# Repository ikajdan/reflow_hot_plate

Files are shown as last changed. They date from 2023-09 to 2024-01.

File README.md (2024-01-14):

<h1 align="center">
  Reflow Hot Plate
  <br><br>
  Reflow Hot Plate
  <br><br>
</h1>

<p align="center">
  <a href="#features">Features</a> •
  <a href="#hardware">Hardware</a> •
  <a href="#firmware">Firmware</a> •
  <a href="#usage">Usage</a> •
  <a href="#gallery">Gallery</a> •
  <a href="#license">License</a>
</p>

The STM32-Based Reflow Hot Plate Project is an open-source initiative aimed at creating a reflow soldering hot plate using the STM32 microcontroller. This project provides an affordable and customizable solution for hobbyists looking to solder surface-mount components onto printed circuit boards with precision and control.

## Features

- **Precise temperature control:** The STM32 microcontroller provides accurate temperature control, ensuring optimal soldering results for a wide range of solder pastes and components.
- **User-friendly interface:** A user-friendly interface, featuring an OLED display and tactile buttons, allows you to easily set and monitor reflow profiles.
- **Customizable reflow profiles:** Create, edit, and save reflow profiles tailored to your specific soldering requirements.
- **Safety mechanisms:** Built-in safety features, such as over-temperature protection and emergency shut-off, ensure a secure soldering environment.
- **Open-source:** The entire project, including schematics, PCB layouts, and firmware is open-source and available for improvement and customization.

## Hardware

The electronic hardware is designed using KiCad. It includes the following components:

- STM32 microcontroller (STM32F103 series)
- N-Channel Power MOSFET for controlling the heating element
- Thermocouple and PT100 sensor for temperature measurement
- OLED display for real-time temperature and soldering progress information
- Buttons for user interaction
- USB-C connector for communication
- Power supply circuitry

The mechanical hardware is designed using FreeCAD. It includes the following components:

- Front panel mask
- Front panel brackets
- Gooseneck mounting

These components are designed to be 3D printed and assembled together to create a complete device.

For detailed hardware schematics, PCB layout and CAD models, please refer to the [Hardware](hardware/) directory.

## Firmware

The firmware for the reflow hot plate is developed using the STM32CubeIDE. It includes:

- Temperature control algorithm
- User interface logic
- Reflow profile management
- Safety and emergency handling

The Cube project can be found in the [Firmware](firmware/) directory.

## Usage

1. Power on the reflow hot plate and wait for it to initialize.
1. Place your PCB with solder paste and components onto the hot plate.
1. Use the tactile buttons and OLED display to navigate through the user interface and select a reflow profile.
1. The hot plate will execute the selected reflow profile, precisely controlling the temperature to solder the components onto the PCB.
1. Once the reflow process is complete, allow the PCB to cool before removing it from the hot plate.

## Gallery








## License

This project is licensed under the [MIT License](LICENSE.md), which means you are free to use, modify, and distribute the project's source code and documentation for both commercial and non-commercial purposes.

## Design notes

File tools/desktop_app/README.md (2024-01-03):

# Reflow Hot Plot

Allows visualizing the temperature profile of a reflow soldering process.

### Usage

```bash
python reflow_hot_plot.py <serial_port>
```

### Testing

1. Set up a virtual serial port: `socat -d -d pty,raw,echo=0 pty,raw,echo=0`
1. Start the application: `python reflow_hot_plot.py /dev/pts/1`
1. Run the device emulator: `python device_emulator.py /dev/pts/2`

## API Specification

The API specification for communication between a dedicated desktop application and the device via the USB CDC interface.

### Send

Commands for controlling the device.

- 1 - starts the soldering procedure `[char]`.
- 0 - stops the soldering procedure `[char]`.

### Receive

Data received from the device.

- Duration - time in seconds since the start of the soldering procedure `[int]`.
- TC - thermocouple temperature in centigrade `[int]`.
- RTD - RTD temperature in centigrade `[int]`.
- Temperature - measured temperature in centigrade `[int]`.
- TargetTemperature - reference temperature in degrees Celsius `[int]`.
- Name - profile name `[string]`.
- Stage - heating stage (0=preheat, 1=soak, 2=reflow, 3=cooldown, 4=idle) `[int]`.
- State - device state (0=welcome, 1=menu, 2=precheck, 3=heating, 4=done, 5=aborted, 6=error) `[int]`.

Example message:

```json
{
  "Duration": 1098,
  "TC": 2350,
  "RTD": 2101,
  "Temperature": 2350,
  "TargetTemperature": 0,
  "Name": "DSP863",
  "Stage": 0,
  "State": 3
}
```

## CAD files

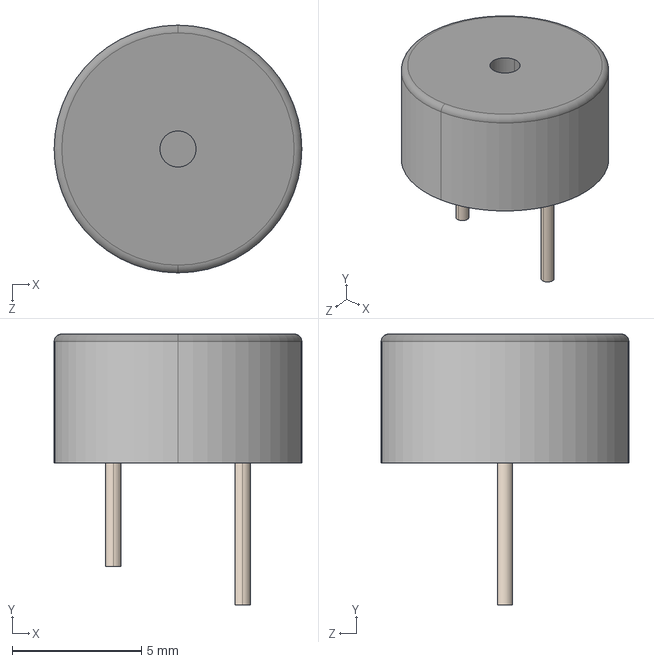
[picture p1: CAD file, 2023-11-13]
hardware/control_board/models/CMI-9605IC-0380T.step
9.60 x 10.5 x 9.60 mm

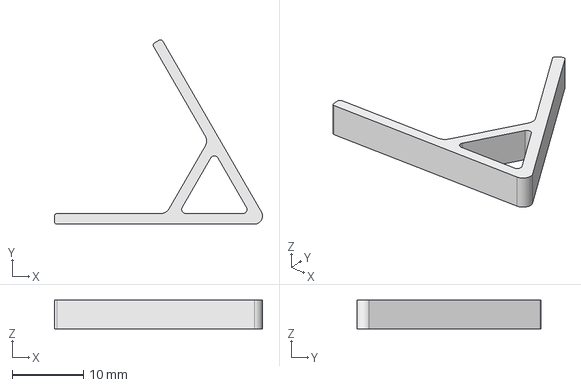
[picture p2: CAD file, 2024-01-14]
hardware/mechanical_parts/front_panel_bracket.FCStd
29.2 x 25.9 x 4.00 mm

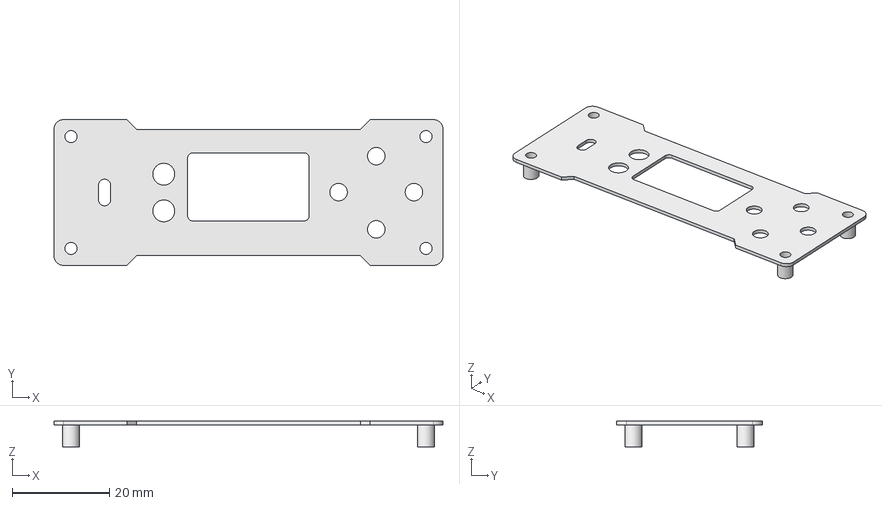
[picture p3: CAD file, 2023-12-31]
hardware/mechanical_parts/front_panel_mask.FCStd
80.0 x 30.0 x 5.30 mm

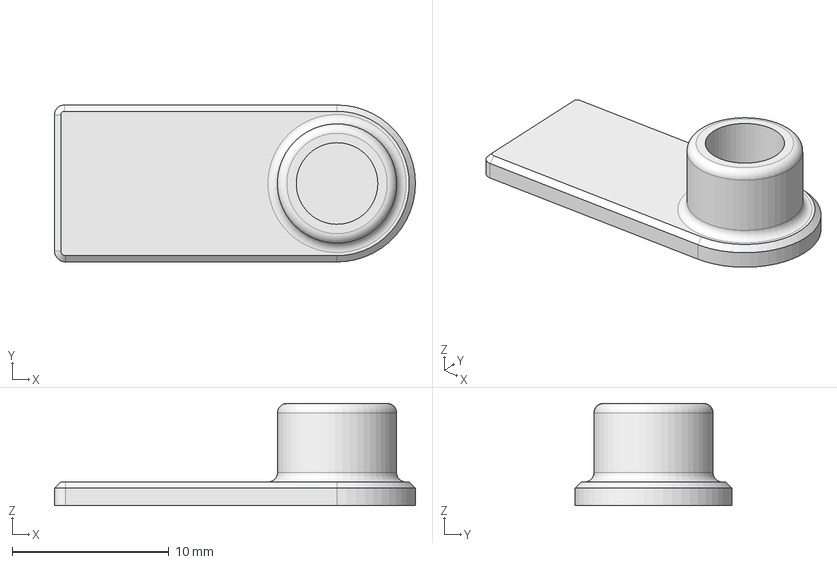
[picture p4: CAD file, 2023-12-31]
hardware/mechanical_parts/gooseneck_mounting.FCStd
23.0 x 10.00 x 6.50 mm

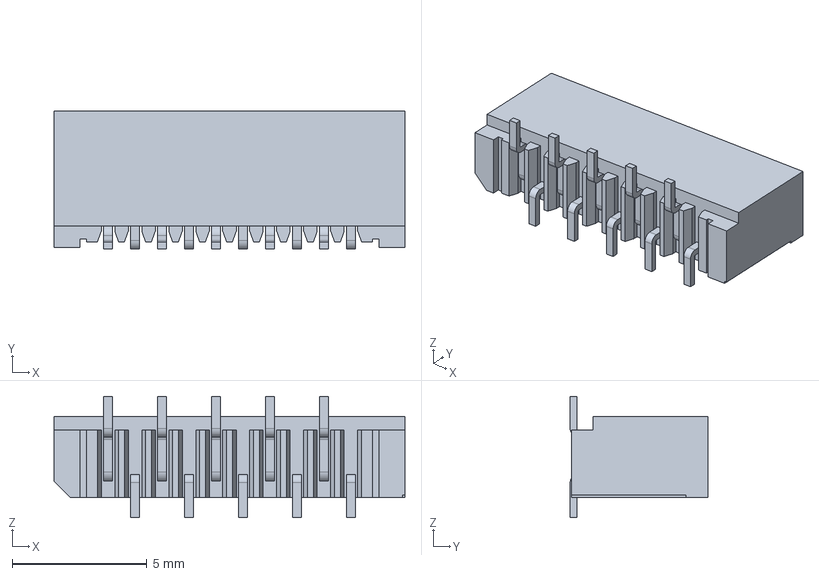
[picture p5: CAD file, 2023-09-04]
hardware/front_panel/models/52808-1070.step
13.0 x 5.10 x 4.50 mm

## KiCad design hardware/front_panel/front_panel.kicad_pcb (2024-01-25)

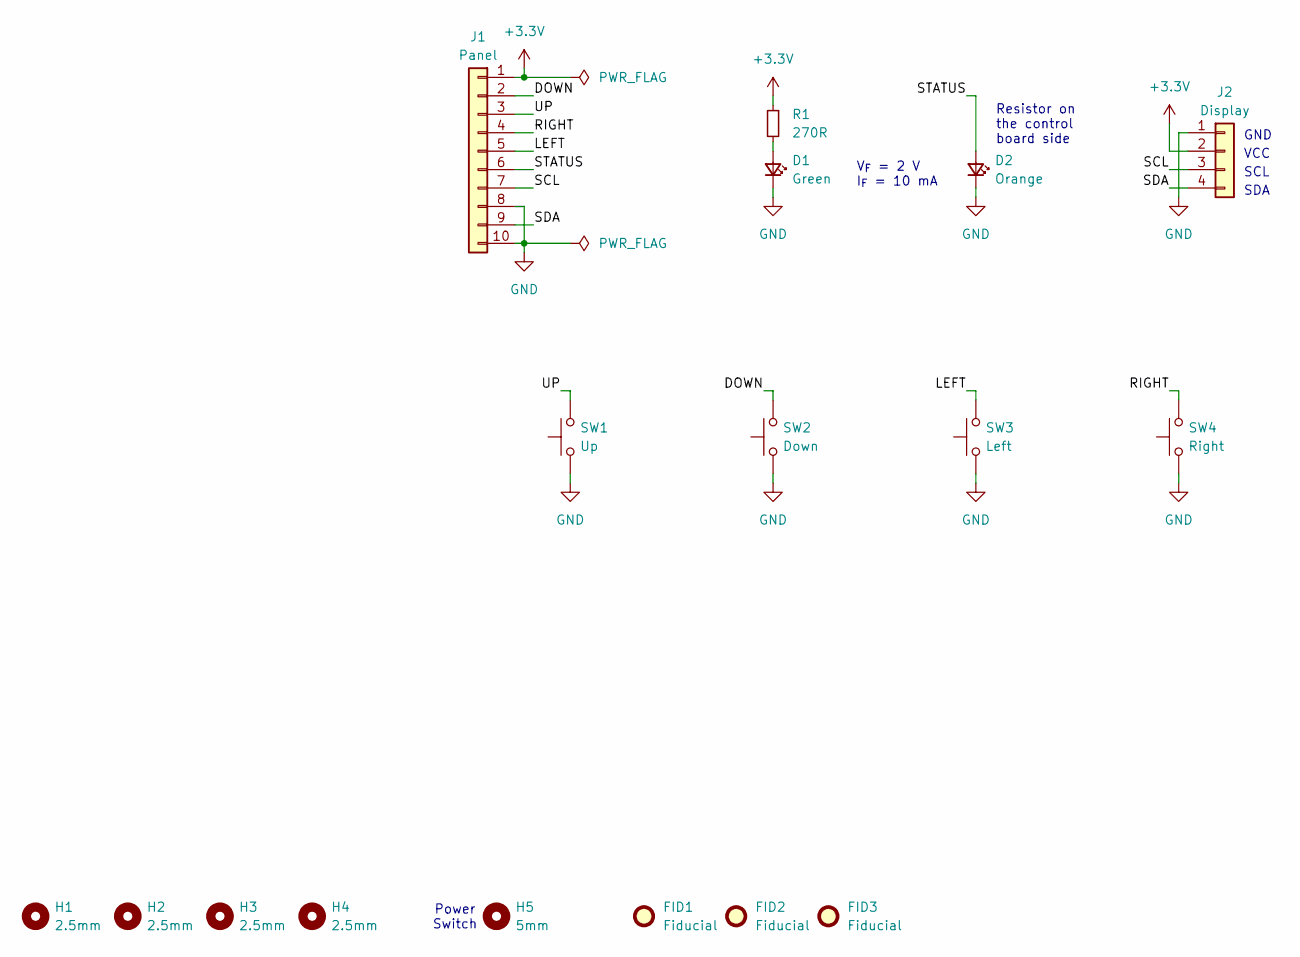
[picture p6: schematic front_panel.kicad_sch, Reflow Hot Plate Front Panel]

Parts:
D1: Green; LED_D3.0mm_FlatTop
D2: Orange; LED_D3.0mm_FlatTop
FID1, FID2, FID3: Fiducial; Fiducial_1mm_Mask2mm
H1, H2, H3, H4: 2.5mm; MountingHole_2.5mm
H5: 5mm; MountingHole_5mm
J1: Panel; 52808-1070
J2: Display; 0.96_OLED
R1: 270R; R_0603_1608Metric
SW1: Up; SW_PUSH_6mm_H7.3mm
SW2: Down; SW_PUSH_6mm_H7.3mm
SW3: Left; SW_PUSH_6mm_H7.3mm
SW4: Right; SW_PUSH_6mm_H7.3mm

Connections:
+3.3V: J1.1, J2.2, R1.1
/DOWN: J1.2, SW2.2
/LEFT: J1.5, SW3.2
/RIGHT: J1.4, SW4.2
/SCL: J1.7, J2.3
/SDA: J1.9, J2.4
/STATUS: D2.2 (A), J1.6
/UP: J1.3, SW1.2
GND: D1.1 (K), D2.1 (K), J1.8, J1.10, J2.1, SW1.1, SW2.1, SW3.1, SW4.1
unnamed: D1.2 (A), R1.2

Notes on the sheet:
Resistor on the control board side
Power Switch
SCL
GND
SDA
VCC
V_{F} = 2 V I_{F} = 10 mA

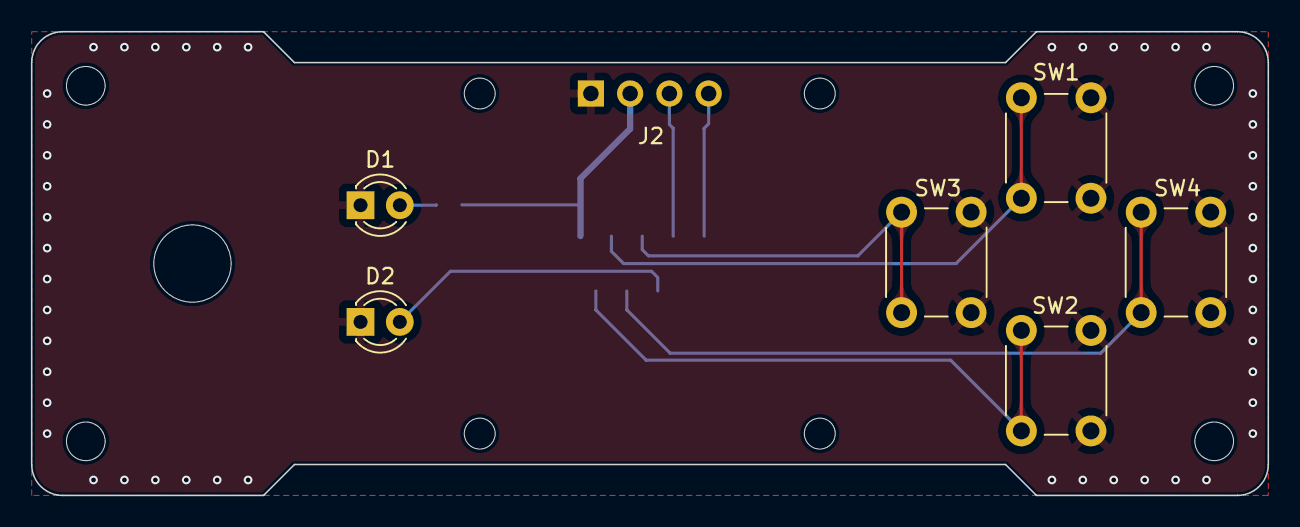
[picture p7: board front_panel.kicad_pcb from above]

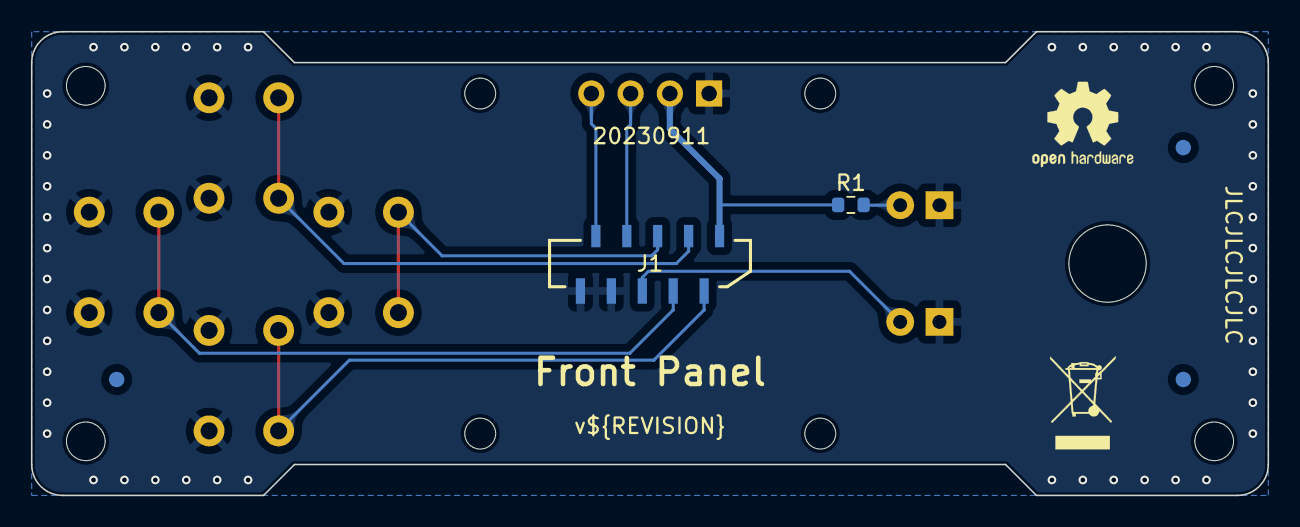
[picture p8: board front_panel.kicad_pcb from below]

Board: 2 copper layers, 80.0 x 30.0 mm, 17 parts (5 on the bottom side), 10 nets.

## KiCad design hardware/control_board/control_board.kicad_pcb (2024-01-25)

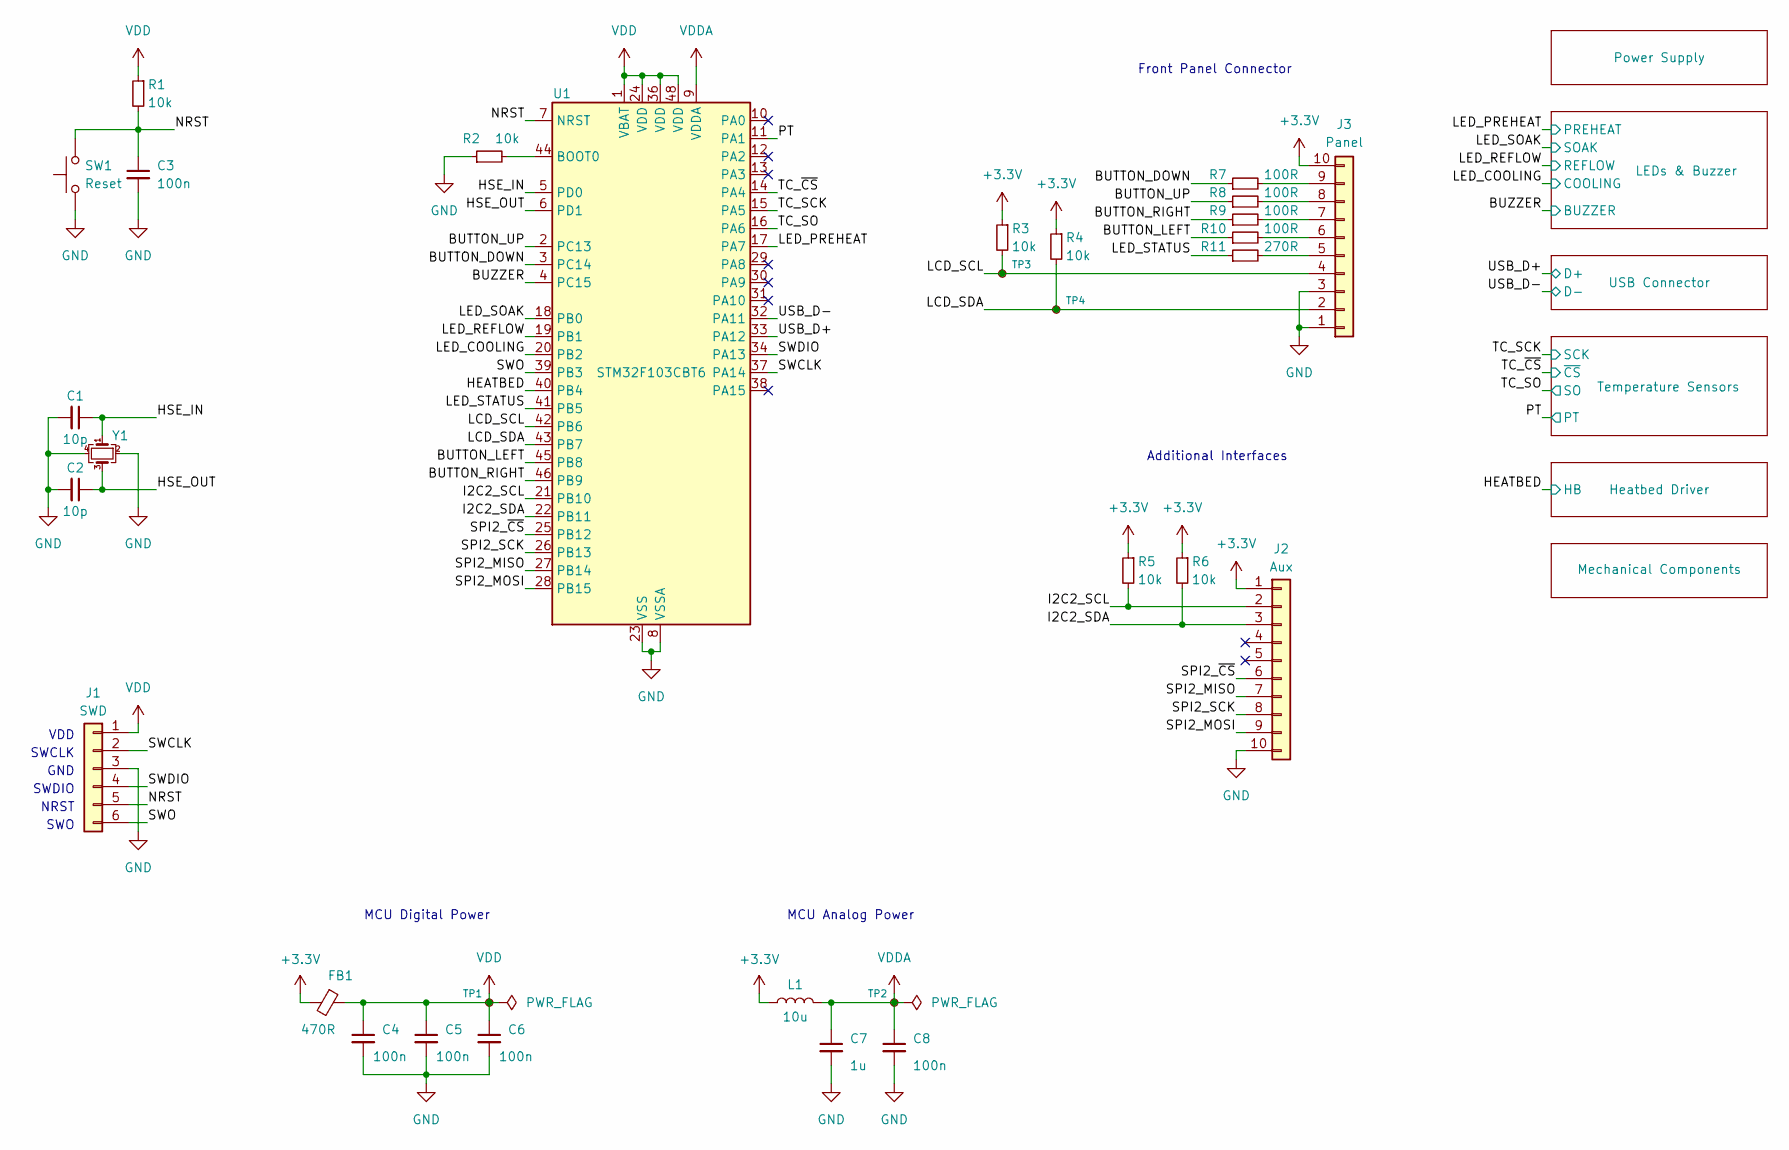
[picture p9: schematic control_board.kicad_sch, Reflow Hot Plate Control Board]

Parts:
C1, C2: 10p; C_0603_1608Metric
C3, C4, C5, C6, C8: 100n; C_0603_1608Metric
C7: 1u; C_0603_1608Metric
FB1: 470R; L_0603_1608Metric
J1: SWD; PinHeader_1x06_P2.54mm_Vertical
J2: Aux; PinHeader_2x05_P2.54mm_Vertical
J3: Panel; 52808-1070
L1: 10u; L_0603_1608Metric
R1, R2, R3, R4, R5, R6: 10k; R_0603_1608Metric
R7, R8, R9, R10: 100R; R_0603_1608Metric
R11: 270R; R_0603_1608Metric
SW1: Reset; SW_SPST_B3U-1000P
TP1, TP2, TP3, TP4: TestPoint_Small; TestPoint_Pad_D1.0mm
U1: STM32F103CBT6; LQFP-48_7x7mm_P0.5mm
Y1: 8MHz; Crystal_SMD_3225-4Pin_3.2x2.5mm

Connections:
+3.3V: FB1.2, J2.1, J3.10, L1.1, R3.1, R4.1, R5.1, R6.1; also elsewhere on the board
/BUTTON_DOWN: R7.1, U1.3 (PC14)
/BUTTON_LEFT: R10.1, U1.45 (PB8)
/BUTTON_RIGHT: R9.1, U1.46 (PB9)
/BUTTON_UP: R8.1, U1.2 (PC13)
/BUZZER: U1.4 (PC15); also elsewhere on the board
/HEATBED: U1.40 (PB4); also elsewhere on the board
/HSE_IN: C1.1, U1.5 (PD0), Y1.1
/HSE_OUT: C2.1, U1.6 (PD1), Y1.3
/I2C2_SCL: J2.2, R5.2, U1.21 (PB10)
/I2C2_SDA: J2.3, R6.2, U1.22 (PB11)
/LCD_SCL: J3.4, R3.2, TP3.1, U1.42 (PB6)
/LCD_SDA: J3.2, R4.2, TP4.1, U1.43 (PB7)
/LED_COOLING: U1.20 (PB2); also elsewhere on the board
/LED_PREHEAT: U1.17 (PA7); also elsewhere on the board
/LED_REFLOW: U1.19 (PB1); also elsewhere on the board
/LED_SOAK: U1.18 (PB0); also elsewhere on the board
/LED_STATUS: R11.1, U1.41 (PB5)
/NRST: C3.1, J1.5, R1.2, SW1.2, U1.7 (NRST)
/PT: U1.11 (PA1); also elsewhere on the board
/SPI2_MISO: J2.7, U1.27 (PB14)
/SPI2_MOSI: J2.9, U1.28 (PB15)
/SPI2_SCK: J2.8, U1.26 (PB13)
/SPI2_~CS: J2.6, U1.25 (PB12)
/SWCLK: J1.2, U1.37 (PA14)
/SWDIO: J1.4, U1.34 (PA13)
/SWO: J1.6, U1.39 (PB3)
/TC_SCK: U1.15 (PA5); also elsewhere on the board
/TC_SO: U1.16 (PA6); also elsewhere on the board
/TC_~CS: U1.14 (PA4); also elsewhere on the board
/USB_D+: U1.33 (PA12); also elsewhere on the board
/USB_D-: U1.32 (PA11); also elsewhere on the board
GND: C1.2, C2.2, C3.2, C4.2, C5.2, C6.2, C7.2, C8.2, J1.3, J2.10, J3.1, J3.3, R2.1, SW1.1, U1.8 (VSSA), U1.23 (VSS), U1.35 (VSS), U1.47 (VSS), Y1.2, Y1.4; also elsewhere on the board
unnamed: J3.5, R11.2
unnamed: J3.6, R10.2
unnamed: J3.7, R9.2
unnamed: J3.8, R8.2
unnamed: J3.9, R7.2
unnamed: R2.2, U1.44 (BOOT0)
VDD: C4.1, C5.1, C6.1, FB1.1, J1.1, R1.1, TP1.1, U1.1 (VBAT), U1.24 (VDD), U1.36 (VDD), U1.48 (VDD); also elsewhere on the board
VDDA: C7.1, C8.1, L1.2, TP2.1, U1.9 (VDDA)

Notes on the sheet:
MCU Analog Power
MCU Digital Power
Additional Interfaces
VDD
SWO
SWCLK
Front Panel Connector
SWDIO
NRST
GND

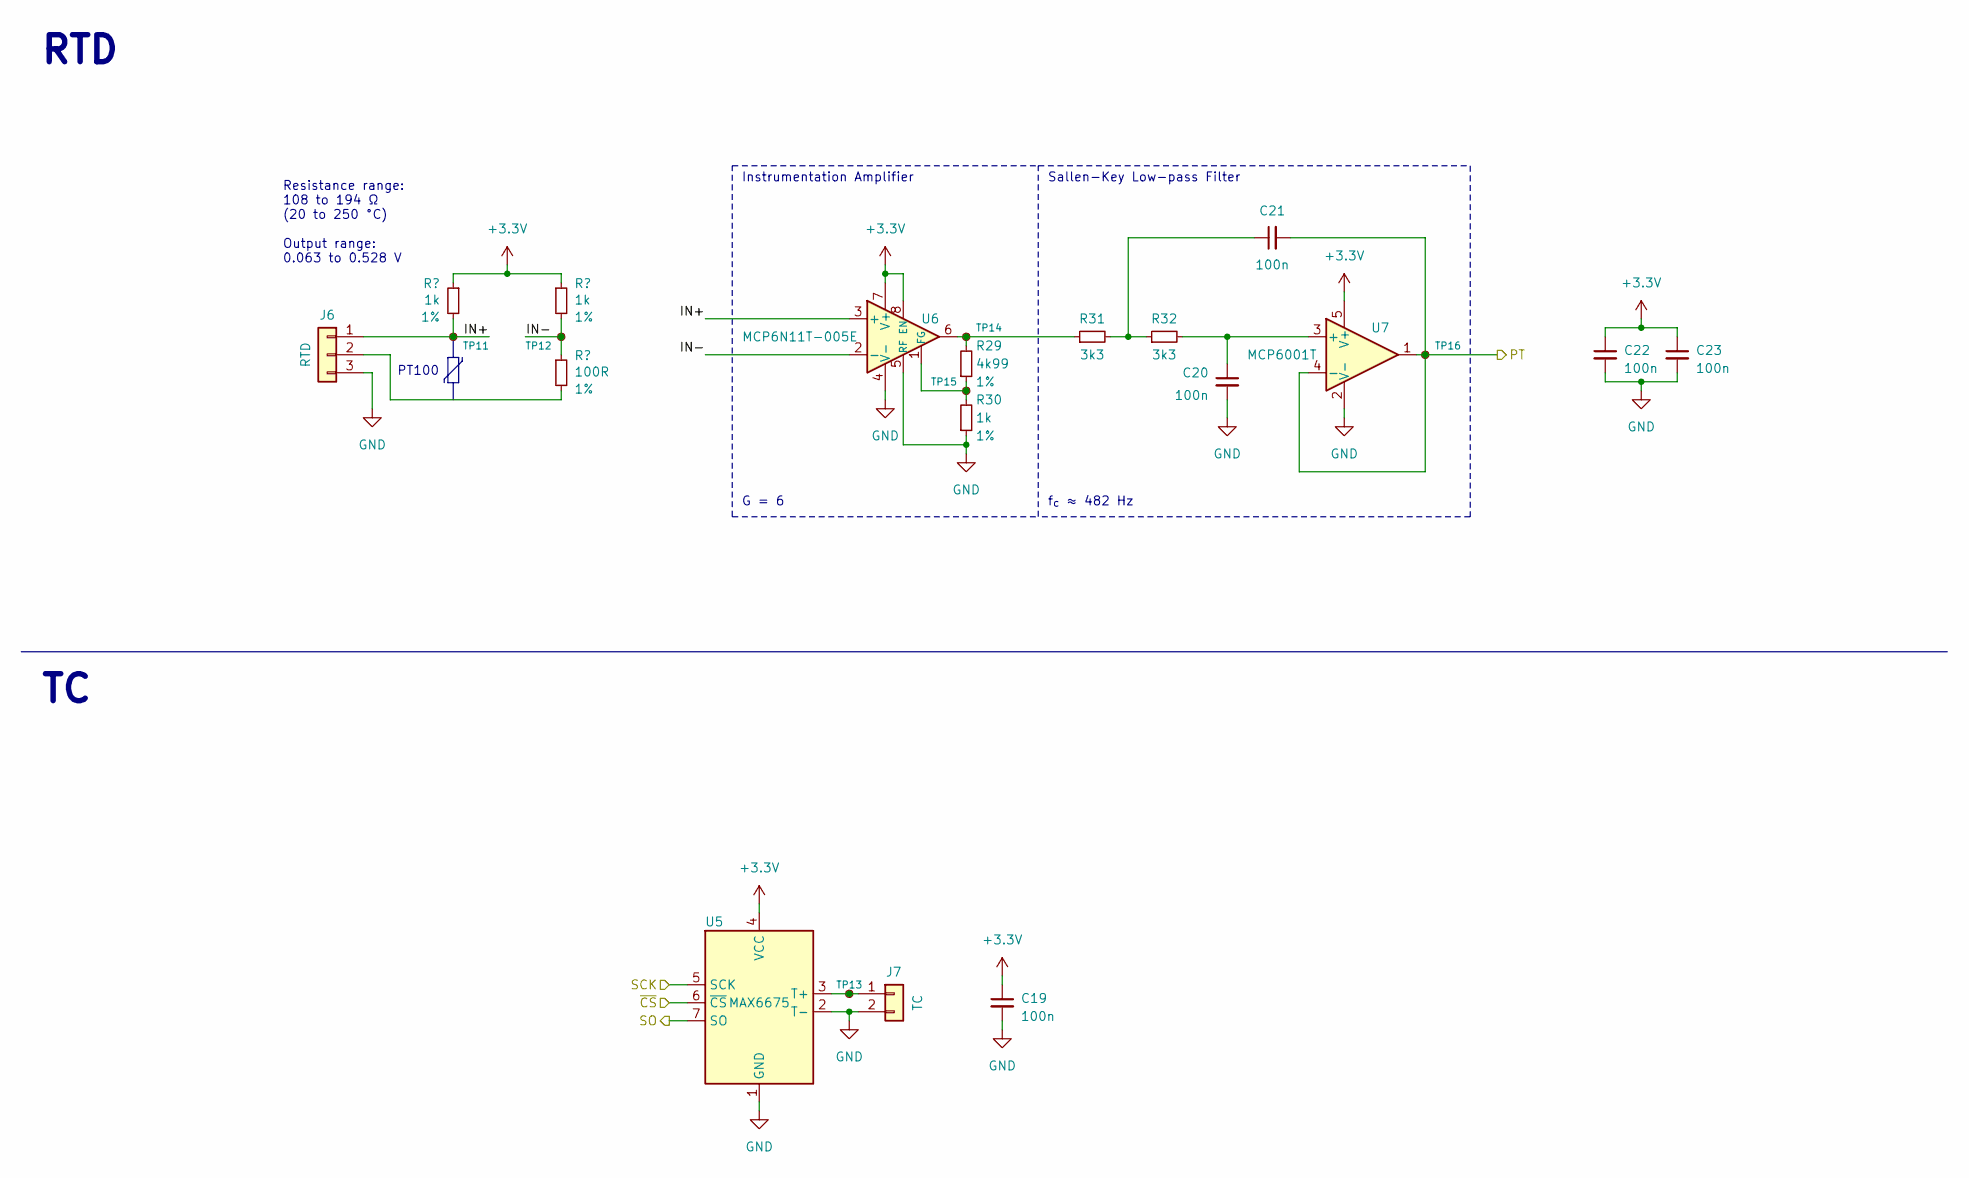
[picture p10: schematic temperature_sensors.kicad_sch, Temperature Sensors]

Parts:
C19, C20, C21, C22, C23: 100n; C_0603_1608Metric
J6: RTD; JST_XH_B3B-XH-A_1x03_P2.50mm_Vertical
J7: TC; JST_XH_B2B-XH-A_1x02_P2.50mm_Vertical
R26, R27, R30: 1k; R_0603_1608Metric; Tolerance 1%
R28: 100R; R_0603_1608Metric; Tolerance 1%
R29: 4k99; R_0603_1608Metric; Tolerance 1%
R31, R32: 3k3; R_0603_1608Metric
TP11, TP12, TP13, TP14, TP15, TP16: TestPoint_Small; TestPoint_Pad_D1.0mm
U5: MAX6675; SOIC-8_3.9x4.9mm_P1.27mm
U6: MCP6N11T-005E; SOIC-8_3.9x4.9mm_P1.27mm
U7: MCP6001T; SOT-23-5

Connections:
+3.3V: C19.1, C22.1, C23.1, R26.1, R27.1, U5.4 (VCC), U6.7 (V+), U6.8 (EN), U7.5 (V+); also elsewhere on the board
/PT: C21.2, TP16.1, U7.1, U7.4 (-); also elsewhere on the board
/TC_SCK: U5.5 (SCK); also elsewhere on the board
/TC_SO: U5.7 (SO); also elsewhere on the board
/TC_~CS: U5.6 (~CS); also elsewhere on the board
/Temperature Sensors/IN+: J6.1, R26.2, TP11.1, U6.3 (+)
/Temperature Sensors/IN-: R27.2, R28.1, TP12.1, U6.2 (-)
GND: C19.2, C20.2, C22.2, C23.2, J6.3, J7.2, R30.1, U5.1 (GND), U5.2 (T-), U6.4 (V-), U6.5 (RF), U7.2 (V-); also elsewhere on the board
unnamed: C21.1, R31.2, R32.1
unnamed: J6.2, R28.2
unnamed: J7.1, TP13.1, U5.3 (T+)
unnamed: R29.2, R31.1, TP14.1, U6.6
unnamed: R29.1, R30.2, TP15.1, U6.1 (FG)
unnamed: C20.1, R32.2, U7.3 (+)

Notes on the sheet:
Instrumentation Amplifier
Resistance range: 108 to 194 Ω (20 to 250 °C) Output range: 0.063 to 0.528 V
G = 6
RTD
Sallen-Key Low-pass Filter
f_{c} ≈ 482 Hz
PT100

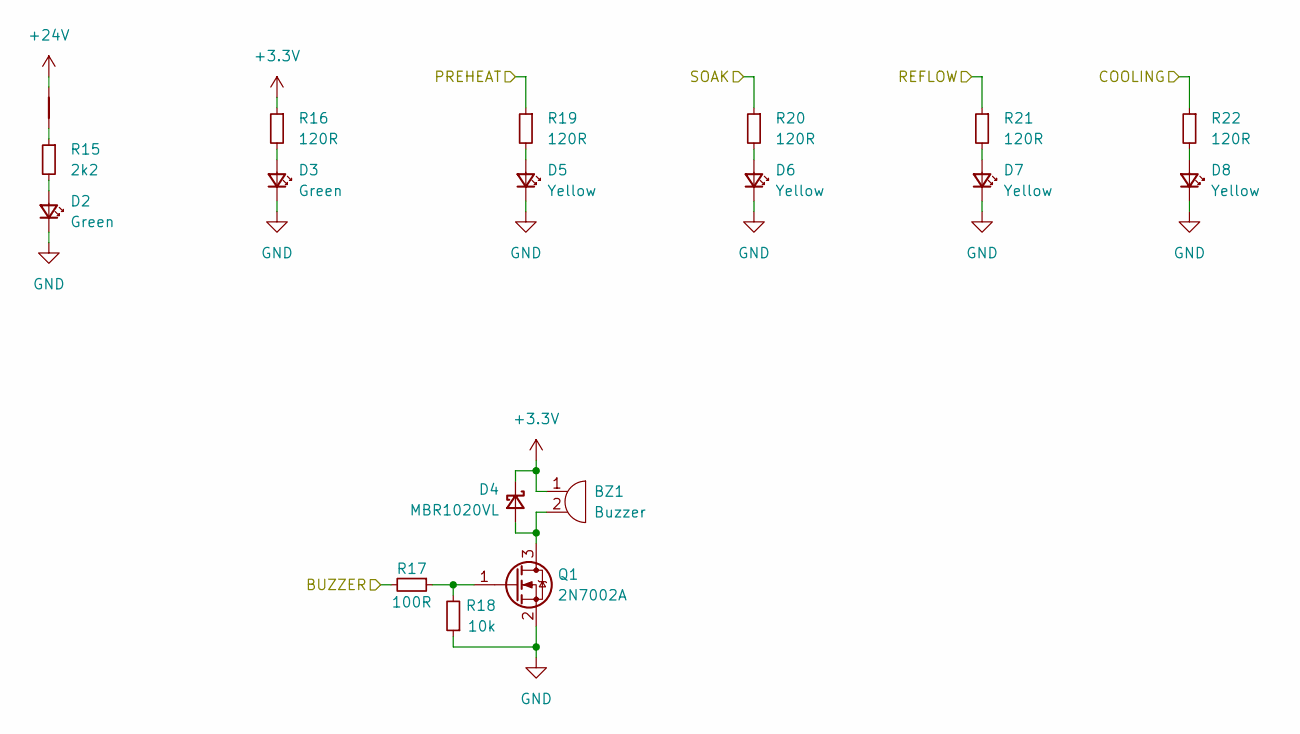
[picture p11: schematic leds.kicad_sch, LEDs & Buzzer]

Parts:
BZ1: Buzzer; CMI-9605IC-0380T
D2, D3: Green; LED_0603_1608Metric
D4: MBR1020VL; D_SOD-123F
D5, D6, D7, D8: Yellow; LED_0603_1608Metric
NT1: NetTie_2; NetTie-2_SMD_Pad0.2mm
Q1: 2N7002A; SOT-23
R15: 2k2; R_0603_1608Metric
R16, R19, R20, R21, R22: 120R; R_0603_1608Metric
R17: 100R; R_0603_1608Metric
R18: 10k; R_0603_1608Metric

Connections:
+3.3V: BZ1.1, D4.1 (K), R16.1; also elsewhere on the board
+24V: NT1.2; also elsewhere on the board
/BUZZER: R17.2; also elsewhere on the board
/LED_COOLING: R22.1; also elsewhere on the board
/LED_PREHEAT: R19.1; also elsewhere on the board
/LED_REFLOW: R21.1; also elsewhere on the board
/LED_SOAK: R20.1; also elsewhere on the board
GND: D2.1 (K), D3.1 (K), D5.1 (K), D6.1 (K), D7.1 (K), D8.1 (K), Q1.2 (S), R18.1; also elsewhere on the board
unnamed: D2.2 (A), R15.2
unnamed: D3.2 (A), R16.2
unnamed: BZ1.2, D4.2 (A), Q1.3 (D)
unnamed: D5.2 (A), R19.2
unnamed: D6.2 (A), R20.2
unnamed: D7.2 (A), R21.2
unnamed: D8.2 (A), R22.2
unnamed: NT1.1, R15.1
unnamed: Q1.1 (G), R17.1, R18.2

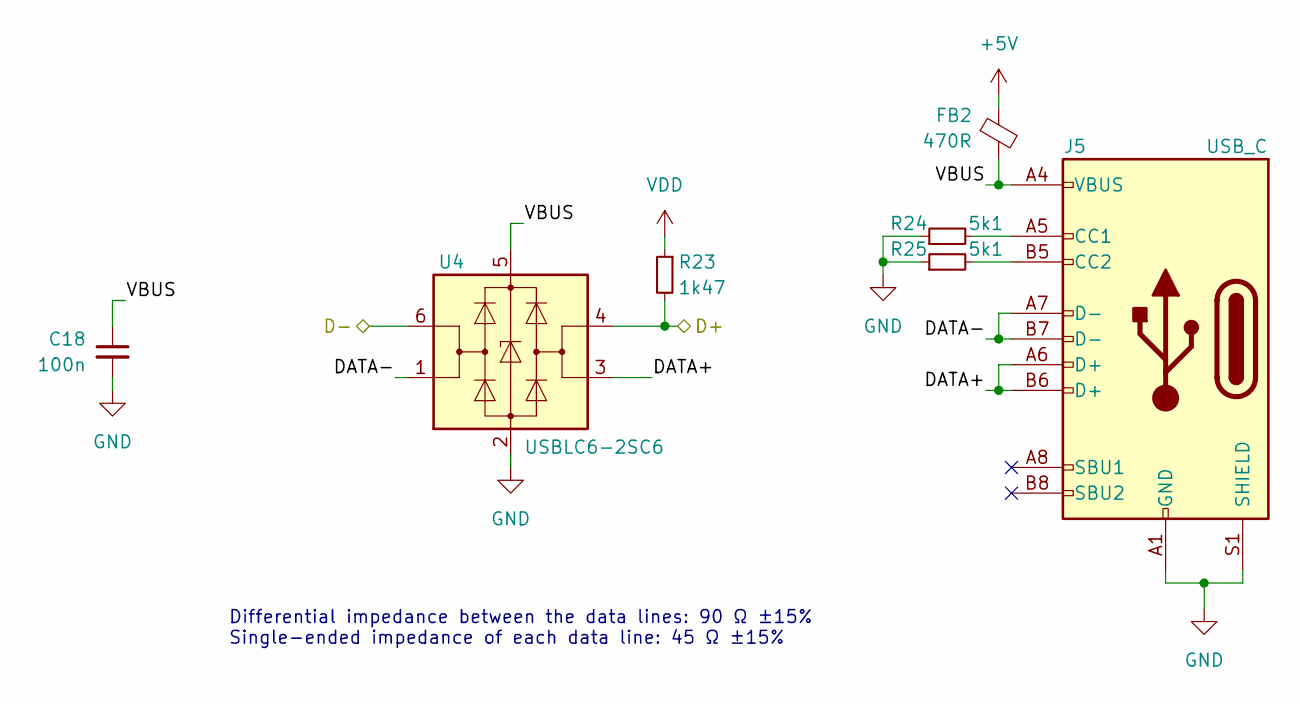
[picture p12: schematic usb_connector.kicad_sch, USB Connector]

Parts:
C18: 100n; C_0603_1608Metric
FB2: 470R; L_0603_1608Metric
J5: USB_C; USB4105-GF-A
R23: 1k47; R_0603_1608Metric
R24, R25: 5k1; R_0603_1608Metric
U4: USBLC6-2SC6; SOT-23-6

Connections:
+5V: FB2.1; also elsewhere on the board
/USB Connector/DATA+: J5.A6 (D+), J5.B6 (D+), U4.3 (I/O2)
/USB Connector/DATA-: J5.A7 (D-), J5.B7 (D-), U4.1 (I/O1)
/USB Connector/VBUS: C18.1, FB2.2, J5.A4 (VBUS), J5.A9 (VBUS), J5.B4 (VBUS), J5.B9 (VBUS), U4.5 (VBUS)
/USB_D+: R23.2, U4.4 (I/O2); also elsewhere on the board
/USB_D-: U4.6 (I/O1); also elsewhere on the board
GND: C18.2, J5.A1 (GND), J5.A12 (GND), J5.B1 (GND), J5.B12 (GND), J5.S1 (SHIELD), R24.1, R25.1, U4.2 (GND); also elsewhere on the board
unnamed: J5.A5 (CC1), R24.2
unnamed: J5.B5 (CC2), R25.2
VDD: R23.1; also elsewhere on the board

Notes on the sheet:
Differential impedance between the data lines: 90 Ω ±15% Single-ended impedance of each data line: 45 Ω ±15%

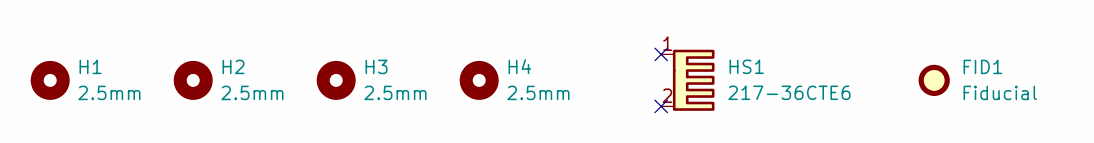
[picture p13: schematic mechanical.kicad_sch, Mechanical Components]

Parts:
FID1: Fiducial; Fiducial_1mm_Mask2mm
H1, H2, H3, H4: 2.5mm; MountingHole_2.5mm
HS1: 217-36CTE6; 217-36CTx6

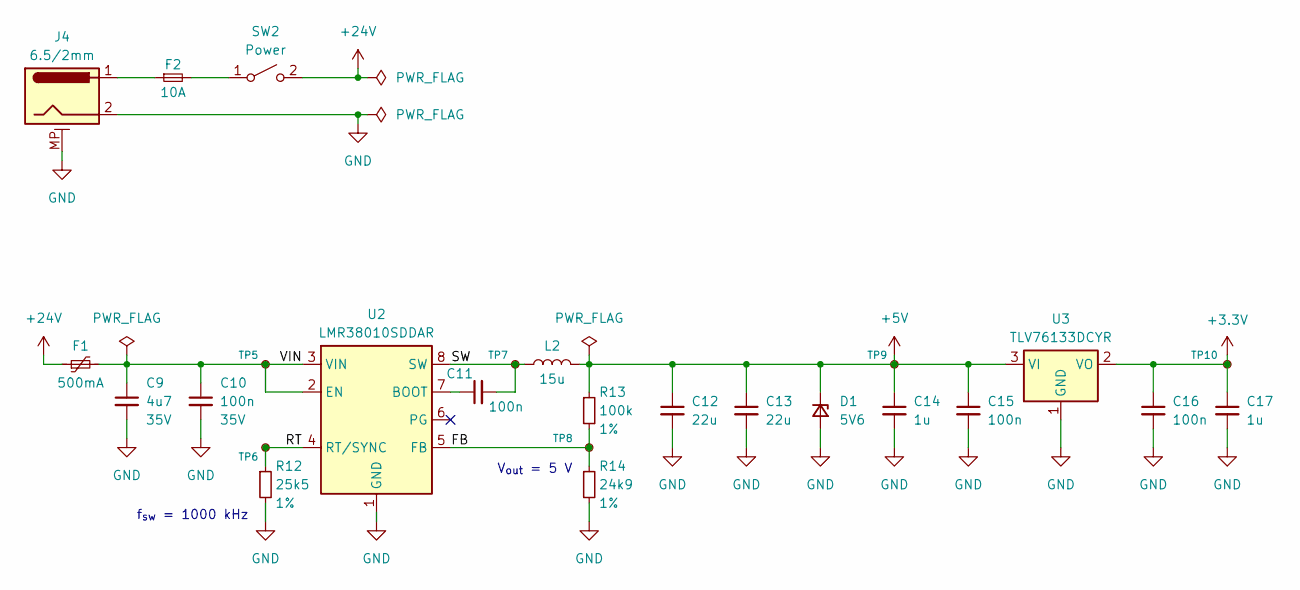
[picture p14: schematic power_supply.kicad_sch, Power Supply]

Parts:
C9: 4u7; C_0603_1608Metric; Rated Voltage 35V
C10: 100n; C_0603_1608Metric; Rated Voltage 35V
C11, C15, C16: 100n; C_0603_1608Metric
C12, C13: 22u; C_0603_1608Metric
C14, C17: 1u; C_0603_1608Metric
D1: 5V6; D_SOD-123F
F1: 500mA; MINISMDCx
F2: 10A; Fuseholder_Cylinder-5x20mm_Schurter_0031_8201_Horizontal_Op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
J4: 6.5/2mm; BarrelJack_CUI_PJ-063AH_Horizontal
L2: 15u; SRN6028Cx
R12: 25k5; R_0603_1608Metric; Tolerance 1%
R13: 100k; R_0603_1608Metric; Tolerance 1%
R14: 24k9; R_0603_1608Metric; Tolerance 1%
SW2: Power; SwitchWireRelief
TP5, TP6, TP7, TP8, TP9, TP10: TestPoint_Small; TestPoint_Pad_D1.0mm
U2: LMR38010SDDAR; TI_SO-PowerPAD-8_ThermalVias
U3: TLV76133DCYR; SOT-223-3_TabPin2

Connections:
+3.3V: C16.1, C17.1, TP10.1, U3.2 (VO); also elsewhere on the board
+5V: C12.1, C13.1, C14.1, C15.1, D1.1 (K), L2.2, R13.1, TP9.1, U3.3 (VI); also elsewhere on the board
+24V: F1.1, SW2.2 (B); also elsewhere on the board
/Power Supply/FB: R13.2, R14.1, TP8.1, U2.5 (FB)
/Power Supply/RT: R12.1, TP6.1, U2.4 (RT/SYNC)
/Power Supply/SW: C11.2, L2.1, TP7.1, U2.8 (SW)
/Power Supply/VIN: C9.1, C10.1, F1.2, TP5.1, U2.2 (EN), U2.3 (VIN)
GND: C9.2, C10.2, C12.2, C13.2, C14.2, C15.2, C16.2, C17.2, D1.2 (A), J4.2, J4.MP (MountPin), R12.2, R14.2, U2.1 (GND), U2.9 (EP), U3.1 (GND); also elsewhere on the board
unnamed: F2.1, J4.1
unnamed: F2.2, SW2.1 (A)
unnamed: C11.1, U2.7 (BOOT)

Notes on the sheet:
f_{sw} = 1000 kHz
V_{out} = 5 V

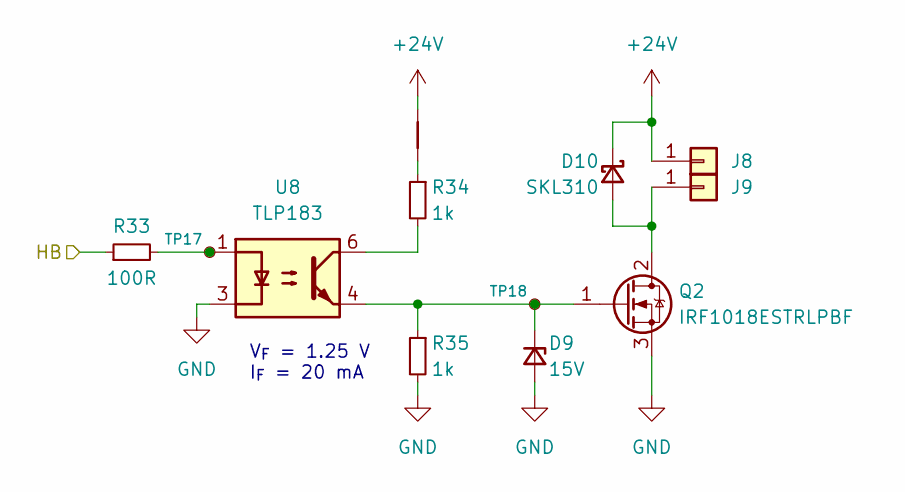
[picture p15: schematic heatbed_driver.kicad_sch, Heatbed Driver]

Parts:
D9: 15V; D_SOD-123F
D10: SKL310; D_SOD-123F
J8, J9: Conn_01x01; Pad_D5mm_H2.2mm_Via
NT2: NetTie_2; NetTie-2_SMD_Pad0.2mm
Q2: IRF1018ESTRLPBF; TO-263-2
R33: 100R; R_0603_1608Metric
R34, R35: 1k; R_0603_1608Metric
TP17, TP18: TestPoint_Small; TestPoint_Pad_D1.0mm
U8: TLP183; SOIC-4_4.55x3.7mm_P2.54mm

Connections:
+24V: D10.1 (K), J8.1, NT2.2; also elsewhere on the board
/HEATBED: R33.1; also elsewhere on the board
GND: D9.2 (A), Q2.3 (S), R35.2, U8.3; also elsewhere on the board
unnamed: D9.1 (K), Q2.1 (G), R35.1, TP18.1, U8.4
unnamed: D10.2 (A), J9.1, Q2.2 (D)
unnamed: NT2.1, R34.1
unnamed: R33.2, TP17.1, U8.1
unnamed: R34.2, U8.6

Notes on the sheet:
V_{F} = 1.25 V I_{F} = 20 mA

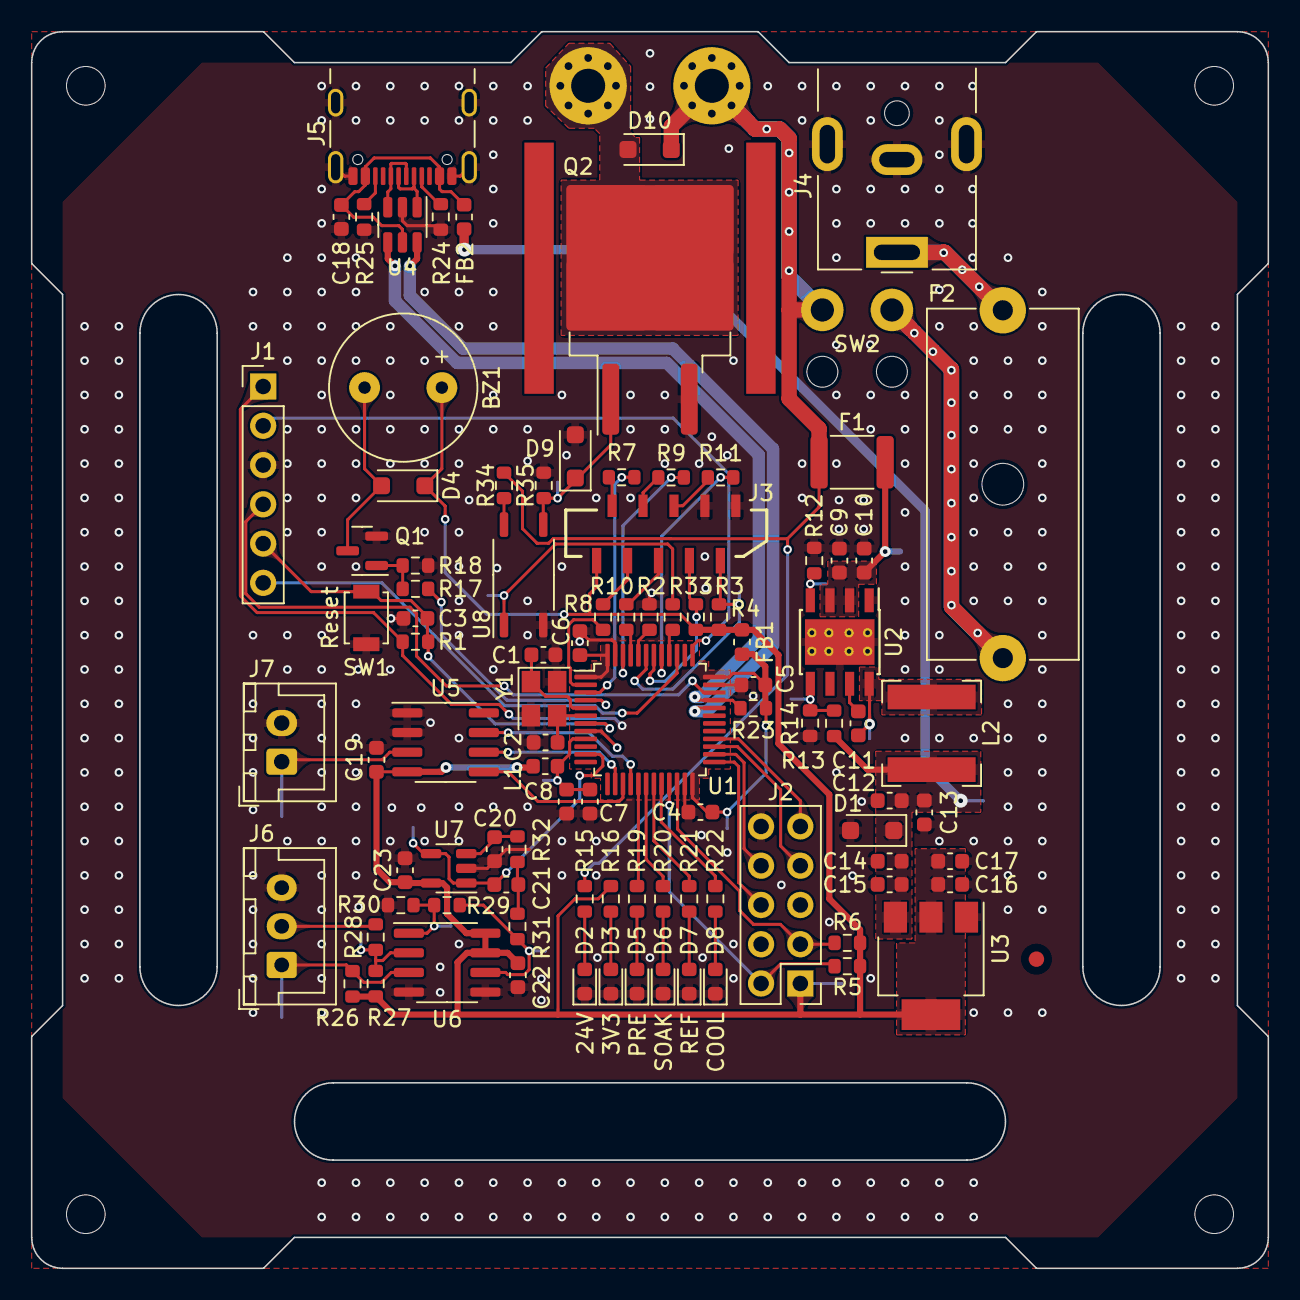
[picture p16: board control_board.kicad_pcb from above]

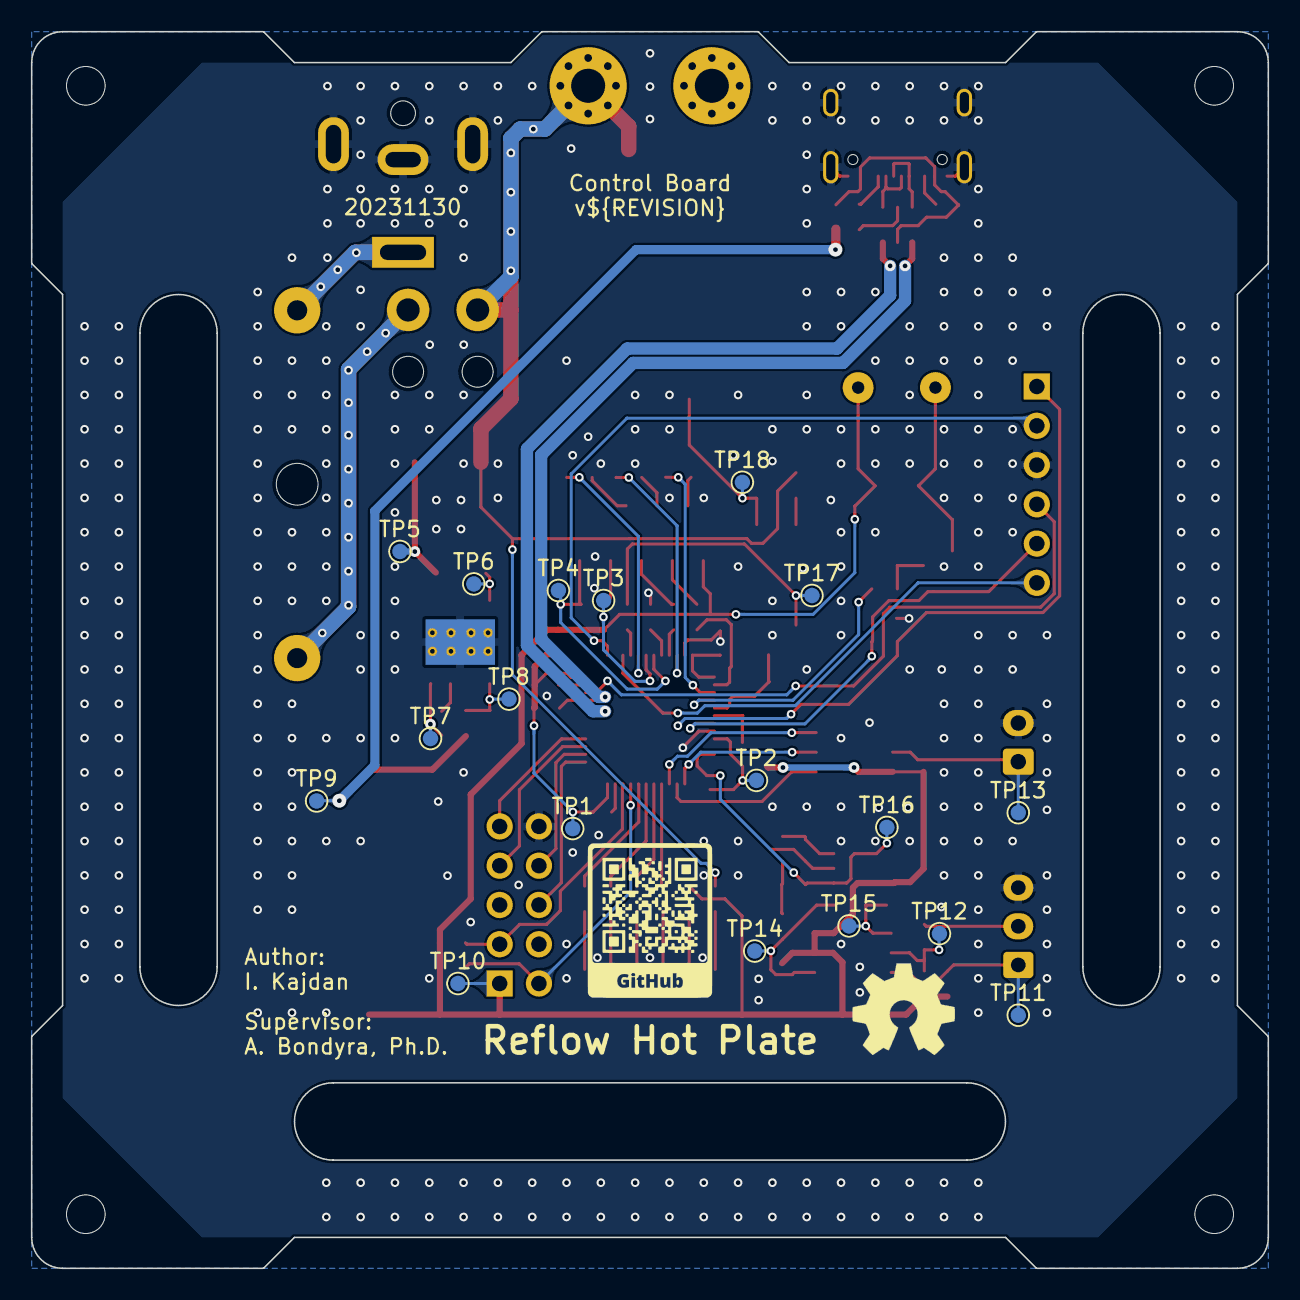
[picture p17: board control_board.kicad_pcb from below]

Board: 2 copper layers, 80.0 x 80.0 mm, 123 parts (18 on the bottom side), 77 nets.

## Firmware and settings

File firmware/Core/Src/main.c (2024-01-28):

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
/* Includes ------------------------------------------------------------------*/
#include "main.h"
#include "adc.h"
#include "dma.h"
#include "i2c.h"
#include "iwdg.h"
#include "spi.h"
#include "tim.h"
#include "usb_device.h"
#include "gpio.h"

/* USER CODE BEGIN Includes */
#include "menu.h"
#include "fsm.h"
#include "disp.h"
#include "ssd1306.h"
#include "max6675.h"
#include "rtd.h"
#include "pid.h"
#include "pwm.h"
#include "led.h"
#include "com.h"
#include <stdbool.h>
#include <stdio.h>
/* USER CODE END Includes */


void SystemClock_Config(void);
/**
 * @brief  The application entry point.
 * @retval int
 */
int main(void)
{
    /* MCU Configuration--------------------------------------------------------*/

    /* Reset of all peripherals, Initializes the Flash interface and the Systick. */
    HAL_Init();

    /* Configure the system clock */
    SystemClock_Config();

    /* Initialize all configured peripherals */
    MX_GPIO_Init();
    MX_DMA_Init();
    MX_ADC1_Init();
    MX_I2C1_Init();
    MX_I2C2_Init();
    MX_SPI1_Init();
    MX_SPI2_Init();
    MX_TIM1_Init();
    MX_TIM2_Init();
    MX_TIM3_Init();
    MX_TIM4_Init();
    MX_USB_DEVICE_Init();
    MX_IWDG_Init();
    /* USER CODE BEGIN 2 */
    HAL_ADCEx_Calibration_Start(&hadc1);
    HAL_ADC_Start_DMA(&hadc1, (uint32_t*)RTD_ADC_REGISTER, RTD_SAMPLES);

    HAL_TIM_Base_Start_IT(&htim1); // (10 Hz) Control loop
    HAL_TIM_Base_Start_IT(&htim2); // (10 Hz) GUI update
    HAL_TIM_PWM_Start(&htim3, TIM_CHANNEL_1); // (100 Hz) Heatbed driver

    LED_SetState(LED_ON);

    ssd1306_Init();

    MENU_Init(&hmenu);

    HAL_GPIO_WritePin(MAX6675_CS_PORT, MAX6675_CS_PIN, GPIO_PIN_SET);
    HAL_GPIO_WritePin(BUZZER_GPIO_Port, BUZZER_Pin, GPIO_PIN_SET);
    /* USER CODE END 2 */

    /* Infinite loop */
    /* USER CODE BEGIN WHILE */
    while(1) {
        // Redraw the screen
        if(LCD_REDRAW) {
            LCD_REDRAW = false;
            ssd1306_Fill(Black);

            switch(hfsm.state) {
                case FSM_WELCOME:
                    LCD_DrawWelcome();
                    break;

                case FSM_MENU:
                    LCD_DrawMenu(&hmenu);
                    break;

                case FSM_PRECHECK:
                    LCD_DrawPrompt(LCD_WAITING);
                    break;

                case FSM_HEATING:
                    LCD_DrawProcessInfo(&hfsm);
                    break;

                case FSM_DONE:
                    LCD_DrawPrompt(LCD_DONE);
                    break;

                case FSM_ABORTED:
                    LCD_DrawPrompt(LCD_ABORTED);
                    break;

                case FSM_ERROR:
                    LCD_DrawPrompt(LCD_ERROR);
                    break;

                default:
                    break;
            }

            ssd1306_UpdateScreen();
        }

        // Receive data from the MAX6675
        MAX6675_ReceiveData();

        // Send a message over the USB CDC
        if(hcom.send_message) {
            hcom.send_message = false;
            COM_SendMsg(&hfsm);
        }
        /* USER CODE END WHILE */

        /* USER CODE BEGIN 3 */
    }
    /* USER CODE END 3 */
}

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
/* USER CODE BEGIN 4 */
/**
 * @brief  Period elapsed callback in non-blocking mode
 * @param  htim: TIM handle
 * @retval None
 */
void HAL_TIM_PeriodElapsedCallback(TIM_HandleTypeDef *htim)
{
    if(htim == &htim1) {
        // Get readings from both sensors (in centigrades)
        hfsm.tc_temperature = MAX6675_GetTemperature();
        hfsm.rtd_temperature = RTD_GetTemperature();

        // Use the higher temperature reading
        hfsm.temperature = (hfsm.tc_temperature > hfsm.rtd_temperature) ? hfsm.tc_temperature : hfsm.rtd_temperature;

        bool error = false;

        // Check for open circuit
        if(hfsm.tc_temperature == MAX6675_TC_OPEN || hfsm.rtd_temperature == RTD_PROBE_OPEN) {
            error = true;
        }

        // Check implasibility of sensor readings
        if(abs(hfsm.tc_temperature - hfsm.rtd_temperature) > TEMPERATURE_IMPL * 100) {
            error = true;
        }

        // Check for temperature out of the range
        if(hfsm.temperature < TEMPERATURE_MIN * 100 || hfsm.temperature > TEMPERATURE_MAX * 100) {
            error = true;
        }

        // Enter an error state if the error flag remains raised for long enough
        if(error) {
            hfsm.error_duration += 1;
            if(hfsm.error_duration > MAXIMUM_CYCLES) {
                hfsm.state = FSM_ERROR;
                hfsm.error_duration = 0;
            }
        } else {
            hfsm.error_duration = 0;
        }

        switch(hfsm.state) {
            case FSM_PRECHECK:
                // Start the process only if the temperature is within the desired range
                if(hfsm.temperature < hfsm.profile[0] * 100 + PRECHECK_DEVIATION * 100) {
                    hfsm.state = FSM_HEATING;
                    hfsm.duration = 0;
                }
                break;

            case FSM_HEATING:
                uint32_t duration_seconds = hfsm.duration / 1000;

                if(duration_seconds < hfsm.profile_duration) {
                    hfsm.target_temperature = hfsm.profile[duration_seconds];
                    hfsm.output = PID_GetOutput(hfsm.temperature / 100.0f, hfsm.target_temperature);

                    // Determine the process stage based on the current time
                    for(int i = 0; i < 4; i++) {
                        if(duration_seconds >= hfsm.stages[i]) {
                            hfsm.stage = i;
                        } else {
                            break;
                        }
                    }
                } else {
                    hfsm.state = FSM_DONE;
                }
                break;

            case FSM_DONE:
                HAL_GPIO_WritePin(BUZZER_GPIO_Port, BUZZER_Pin, GPIO_PIN_SET);
                hfsm.target_temperature = 0;
                hfsm.output = 0;
                break;

            default:
                HAL_GPIO_WritePin(BUZZER_GPIO_Port, BUZZER_Pin, GPIO_PIN_RESET);
                hfsm.target_temperature = 0;
                hfsm.output = 0;
                break;
        }

        PWM_SetDutyCycle(&htim3, TIM_CHANNEL_1, hfsm.output);
        HAL_IWDG_Refresh(&hiwdg); // 200 ms timeout

        hfsm.duration += 100;
    } else if(htim == &htim2) {
        LCD_ScheduleRedraw();

        if(hfsm.state != FSM_WELCOME) {
            // Check if a message has been received
            if(hcom.data_received) {
                hcom.data_received = false;

                if(hcom.buffer[0] == '1') {
                    hfsm.state = FSM_PRECHECK;
                } else if(hcom.buffer[0] == '0') {
                    hfsm.state = FSM_ABORTED;
                }
            }

            if(hfsm.state == FSM_HEATING) {
                LED_SetState(hfsm.stage);
            } else {
                LED_SetState(LED_OFF);
            }

            COM_ScheduleSend();
        } else {
            if(HAL_GetTick() > STARTUP_DELAY) {
                if(hfsm.state == FSM_WELCOME) {
                    hfsm.state = FSM_MENU;
                }
            }
        }
    } else if(htim == &htim4) {
        printf("Stopping TIM4: %lu\n\n", HAL_GetTick());
        HAL_TIM_Base_Stop_IT(&htim4);
        hmenu.debouncing = false;
    }
}

/**
 * @brief  EXTI line detection callbacks
 * @param  GPIO_Pin: Specifies the pins connected EXTI line
 * @retval None
 */
void HAL_GPIO_EXTI_Callback(uint16_t GPIO_Pin)
{
    // Check if buttons are being debounced
    if(hmenu.debouncing) {
        uint32_t counter_value = __HAL_TIM_GET_COUNTER(&htim4);
        uint32_t timer_frequency = HAL_RCC_GetHCLKFreq() / (htim4.Init.Prescaler + 1);
        uint32_t time = (counter_value * 1000) / timer_frequency;
        printf("Debouncing: %lu\n", time);

        return;
    } else {
        // Ignore button callbacks from now on
        printf("Starting TIM4: %lu\n", HAL_GetTick());
        hmenu.debouncing = true;

        // Clear the interrupt flag, otherwise the update callback will be called
        __HAL_TIM_CLEAR_IT(&htim4, TIM_IT_UPDATE);
        __HAL_TIM_SET_COUNTER(&htim4, 0);

        HAL_TIM_Base_Start_IT(&htim4); // 100 ms
    }

    // Handle button events based on the current state
// @formatter:off
    switch(hfsm.state) {
        case FSM_WELCOME:
        case FSM_DONE:
        case FSM_ABORTED:
        case FSM_ERROR:
        case FSM_PRECHECK:
            HAL_GPIO_WritePin(BUZZER_GPIO_Port, BUZZER_Pin, GPIO_PIN_RESET);
            hfsm.state = FSM_MENU;
            return;

        default:
            break;
    }
// @formatter:on

    switch(hfsm.state) {
        case FSM_MENU:
            if(GPIO_Pin == BUTTON_UP_Pin) {
                MENU_Prev(&hmenu);
            } else if(GPIO_Pin == BUTTON_DOWN_Pin) {
                MENU_Next(&hmenu);
            } else if(GPIO_Pin == BUTTON_RIGHT_Pin) {
                FSM_SetActiveProfile(&hmenu, &hfsm);
                hfsm.state = FSM_PRECHECK;
            }
            break;

        case FSM_HEATING:
            if(GPIO_Pin == BUTTON_LEFT_Pin) {
                hfsm.state = FSM_ABORTED;
            }
            break;

        default:
            break;
    }
}

/**
 * @brief  SPI RX transfer callback
 * @param  hspi: SPI handle
 * @retval None
 */
void HAL_SPI_RxCpltCallback(SPI_HandleTypeDef *hspi)
{
    if(hspi == &hspi1) {
        MAX6675_CalculateTemperature();
    }
}
/* USER CODE END 4 */
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


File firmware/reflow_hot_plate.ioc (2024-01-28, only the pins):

Mcu.UserName=STM32F103CBTx
PA1.GPIO_Label=PT
PA1.Signal=ADCx_IN1
PA11.GPIO_Label=USB_D-
PA11.Signal=USB_DM
PA12.GPIO_Label=USB_D+
PA12.Signal=USB_DP
PA13.GPIO_Label=SWDIO
PA13.Signal=SYS_JTMS-SWDIO
PA14.GPIO_Label=SWCLK
PA14.Signal=SYS_JTCK-SWCLK
PA4.GPIO_Label=TC_CS
PA4.Signal=GPIO_Output
PA5.GPIO_Label=TC_SCK
PA5.Signal=SPI1_SCK
PA6.GPIO_Label=TC_SO
PA6.Signal=SPI1_MISO
PA7.GPIO_Label=LED_PREHEAT
PA7.Signal=GPIO_Output
PB0.GPIO_Label=LED_SOAK
PB0.Signal=GPIO_Output
PB1.GPIO_Label=LED_REFLOW
PB1.Signal=GPIO_Output
PB10.Signal=I2C2_SCL
PB11.Signal=I2C2_SDA
PB12.GPIO_Label=SPI2_CS
PB12.Signal=GPIO_Output
PB13.Signal=SPI2_SCK
PB14.Signal=SPI2_MISO
PB15.Signal=SPI2_MOSI
PB2.GPIO_Label=LED_COOLING
PB2.Signal=GPIO_Output
PB3.GPIO_Label=SWO
PB3.Signal=SYS_JTDO-TRACESWO
PB4.GPIO_Label=HEATBED
PB4.Signal=S_TIM3_CH1
PB5.GPIO_Label=LED_STATUS
PB5.Signal=GPIO_Output
PB6.GPIO_Label=LCD_SCL
PB6.Signal=I2C1_SCL
PB7.GPIO_Label=LCD_SDA
PB7.Signal=I2C1_SDA
PB8.GPIO_Label=BUTTON_LEFT
PB8.Signal=GPXTI8
PB9.GPIO_Label=BUTTON_RIGHT
PB9.Signal=GPXTI9
PC13-TAMPER-RTC.GPIO_Label=BUTTON_UP
PC13-TAMPER-RTC.Signal=GPXTI13
PC14-OSC32_IN.GPIO_Label=BUTTON_DOWN
PC14-OSC32_IN.Signal=GPXTI14
PC15-OSC32_OUT.GPIO_Label=BUZZER
PC15-OSC32_OUT.Signal=GPIO_Output
PD0-OSC_IN.GPIO_Label=HSE_IN
PD0-OSC_IN.Signal=RCC_OSC_IN
PD1-OSC_OUT.GPIO_Label=HSE_OUT
PD1-OSC_OUT.Signal=RCC_OSC_OUT

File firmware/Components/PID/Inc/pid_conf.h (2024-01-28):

/**
 ******************************************************************************
 * @file           : pid_conf.h
 * @brief          : PID library configuration
 *
 ******************************************************************************
 */

#ifndef __PID_CONFIG_H__
#define __PID_CONFIG_H__

/* Public includes -----------------------------------------------------------*/

/* Public typedefs -----------------------------------------------------------*/

/* Public defines ------------------------------------------------------------*/
/**
 * @brief Proportional gain for the PID controller
 */
#define PID_KP 5.6f

/**
 * @brief Integral gain for the PID controller
 */
#define PID_KI 0.69f

/**
 * @brief Derivative gain for the PID controller
 */
#define PID_KD 0.05f

/**
 * @brief Sampling time for the PID controller
 */
#define PID_TS 100.0f

/**
 * @brief Minimum allowable value for the PID controller output
 */
#define PID_MIN 0.0f

/**
 * @brief Maximum allowable value for the PID controller output
 */
#define PID_MAX 100.0f

/* Public macros -------------------------------------------------------------*/

/* Public variables ----------------------------------------------------------*/

/* Public function prototypes ------------------------------------------------*/

#endif /* __PID_CONFIG_H__ */

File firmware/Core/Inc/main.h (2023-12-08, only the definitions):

#define BUTTON_UP_Pin GPIO_PIN_13
#define BUTTON_UP_GPIO_Port GPIOC
#define BUTTON_UP_EXTI_IRQn EXTI15_10_IRQn
#define BUTTON_DOWN_Pin GPIO_PIN_14
#define BUTTON_DOWN_GPIO_Port GPIOC
#define BUTTON_DOWN_EXTI_IRQn EXTI15_10_IRQn
#define BUZZER_Pin GPIO_PIN_15
#define BUZZER_GPIO_Port GPIOC
#define HSE_IN_Pin GPIO_PIN_0
#define HSE_IN_GPIO_Port GPIOD
#define HSE_OUT_Pin GPIO_PIN_1
#define HSE_OUT_GPIO_Port GPIOD
#define PT_Pin GPIO_PIN_1
#define PT_GPIO_Port GPIOA
#define TC_CS_Pin GPIO_PIN_4
#define TC_CS_GPIO_Port GPIOA
#define TC_SCK_Pin GPIO_PIN_5
#define TC_SCK_GPIO_Port GPIOA
#define TC_SO_Pin GPIO_PIN_6
#define TC_SO_GPIO_Port GPIOA
#define LED_PREHEAT_Pin GPIO_PIN_7
#define LED_PREHEAT_GPIO_Port GPIOA
#define LED_SOAK_Pin GPIO_PIN_0
#define LED_SOAK_GPIO_Port GPIOB
#define LED_REFLOW_Pin GPIO_PIN_1
#define LED_REFLOW_GPIO_Port GPIOB
#define LED_COOLING_Pin GPIO_PIN_2
#define LED_COOLING_GPIO_Port GPIOB
#define SPI2_CS_Pin GPIO_PIN_12
#define SPI2_CS_GPIO_Port GPIOB
#define USB_D__Pin GPIO_PIN_11
#define USB_D__GPIO_Port GPIOA
#define USB_D_A12_Pin GPIO_PIN_12
#define USB_D_A12_GPIO_Port GPIOA
#define SWDIO_Pin GPIO_PIN_13
#define SWDIO_GPIO_Port GPIOA
#define SWCLK_Pin GPIO_PIN_14
#define SWCLK_GPIO_Port GPIOA
#define SWO_Pin GPIO_PIN_3
#define SWO_GPIO_Port GPIOB
#define HEATBED_Pin GPIO_PIN_4
#define HEATBED_GPIO_Port GPIOB
#define LED_STATUS_Pin GPIO_PIN_5
#define LED_STATUS_GPIO_Port GPIOB
#define LCD_SCL_Pin GPIO_PIN_6
#define LCD_SCL_GPIO_Port GPIOB
#define LCD_SDA_Pin GPIO_PIN_7
#define LCD_SDA_GPIO_Port GPIOB
#define BUTTON_LEFT_Pin GPIO_PIN_8
#define BUTTON_LEFT_GPIO_Port GPIOB
#define BUTTON_LEFT_EXTI_IRQn EXTI9_5_IRQn
#define BUTTON_RIGHT_Pin GPIO_PIN_9
#define BUTTON_RIGHT_GPIO_Port GPIOB
#define BUTTON_RIGHT_EXTI_IRQn EXTI9_5_IRQn

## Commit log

2023-03-19 Generate rounded tracks
    [heatbed-rounded.kicad_pcb]
2023-03-19 Adjust tracks' widths
    [heatbed-rounded.kicad_pcb, heatbed.kicad_pcb, heatbed.kicad_sch]
2023-03-19 Add variants with 4 mm spacing
    [heatbed.kicad_pcb, heatbed.kicad_sch]
2023-03-26 Further increase tracks' widths
    [heatbed.kicad_pcb]
2023-04-13 Add a control board
    [control_board.kicad_pcb, control_board.kicad_sch, heatbed.kicad_pcb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]
2023-04-15 Increase holes' diameters
    [heatbed.kicad_pcb, heatbed.kicad_sch]
2023-07-22 Use a dedicated MCU for the control board
    [PKM13EPYH4000-A0.step, USB4105-GF-A.step, control_board.kicad_sch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]
2023-07-22 Add a script for fitting reflow curves
    [dsp_863.csv]
2023-07-23 Improve hot plate PCB design
    [heatbed.kicad_pcb, heatbed.kicad_sch]
2023-07-23 Add rounded track version
    [heatbed-rounded.kicad_pcb]
2023-07-24 Add a clearance around mounting holes
    [heatbed-rounded.kicad_pcb, heatbed.kicad_pcb]
2023-07-26 Adjust component values
    [0914-3-15-20-77-14-11-0.step, control_board.kicad_sch, front_panel.kicad_sch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]
2023-07-27 Use a 3-wire RTD configuration
    [control_board.kicad_sch, heatbed_driver.kicad_sch, temperature_sensors.kicad_sch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]
2023-07-27 Use one-sided pads
    [heatbed-rounded.kicad_pcb, heatbed.kicad_pcb, heatbed.kicad_sch]
2023-07-29 Assign footprints to components
    [52808-1070.stp, control_board.kicad_sch, front_panel.kicad_sch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]
2023-07-30 Remove unused footprint
    [0914-3-15-20-77-14-11-0.step]
2023-07-31 Change mounting holes to M2.5 and use ring terminals
    [heatbed-rounded.kicad_pcb, heatbed.kicad_pcb, heatbed.kicad_sch]
2023-08-12 Place components on the control board PCB
    [PKM13EPYH4000-A0.stp, USB4105-GF-A.step, control_board.kicad_pcb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]
2023-08-12 Remove mounting hole silkscreen circles
    [heatbed-rounded.kicad_pcb, heatbed.kicad_pcb, heatbed.kicad_sch]
2023-08-12 Place components on the front panel PCB
    [front_panel.kicad_pcb, front_panel.kicad_sch]
2023-09-04 Route front panel PCB tracks
    [52808-1070.stp, PKM13EPYH4000-A0.stp, control_board.kicad_pcb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]
2023-09-04 Lock the polygons
    [heatbed-rounded.kicad_pcb, heatbed.kicad_pcb]
2023-09-11 Route control board PCB tracks
    [control_board.kicad_pcb, control_board.kicad_sch, front_panel.kicad_pcb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]
2023-09-11 Fix DRC errors
    [control_board.kicad_pcb, control_board.kicad_sch, front_panel.kicad_pcb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]
2023-09-11 Stitch the ground planes
    [control_board.kicad_pcb, front_panel.kicad_pcb, front_panel.kicad_sch]
2023-09-12 Tidy up vias
    [control_board.kicad_pcb, control_board.kicad_sch]
2023-09-13 Minor layout adjustments
    [PKM13EPYH4000-A0.stp, control_board.kicad_pcb, control_board.kicad_sch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]
2023-09-14 Add vias to the high current tracks
    [control_board.kicad_pcb]
2023-10-29 Cleanup the project
    [control_board.kicad_pcb, control_board.kicad_sch, front_panel.kicad_pcb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]
2023-10-30 Update MCU picture
    [control_board.kicad_sch, heatbed_driver.kicad_sch]
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2023-11-13 Adjust fiducials
    [control_board.kicad_pcb, control_board.kicad_sch, heatbed_driver.kicad_sch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]
2023-11-13 Change the buzzer
    [CMI-9605IC-0380T.stp, PKM13EPYH4000-A0.stp, control_board.kicad_pcb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]
2023-11-14 Add USB D+ pull-up resistor
    [control_board.kicad_pcb, heatbed_driver.kicad_sch, temperature_sensors.kicad_sch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]
2023-11-14 Use Schottky flyback diode for heatbed
    [control_board.kicad_pcb, control_board.kicad_sch, heatbed_driver.kicad_sch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]
2023-11-16 Rename STEP files
    [52808-1070.step, CMI-9605IC-0380T.step, control_board.kicad_pcb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]
2023-11-17 Fix the resistor order in the Wheatstone bridge
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2023-11-27 Remove copper fills around mounting holes
    [control_board.kicad_pcb, control_board.kicad_sch, front_panel.kicad_pcb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]
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2023-11-27 Change MCU to STM32F103CBT6
    [control_board.kicad_pcb, control_board.kicad_sch]
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2023-11-28 Add a script for generating header files of reflow profiles
    [dsp_863.csv]
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2023-11-28 Add temperature drift calibration offset setting
    [max6675.c, max6675_conf.h]
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2023-11-29 Release v1.1
    [control_board.kicad_pcb, control_board.kicad_sch, heatbed_driver.kicad_sch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]
2023-12-04 Remove the JLC placeholder
    [control_board.kicad_pcb]
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2023-12-05 Don't stop the loop when message parsing fails
    [reflow_hot_plot.py]
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2023-12-07 Enumarate the idle state as 0
    [dsp_863.csv]
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2023-12-08 Swap the left and right button signals
    [control_board.kicad_pcb, control_board.kicad_sch, power_supply.kicad_sch]
2023-12-08 Fix an incorrect state check
    [reflow_hot_plot.py]
2023-12-08 Reset appropriate variables when not running
    [main.c]
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2023-12-19 Add more solder paste profiles
    [DSP863.csv, SMDLTLFP.csv, TS991AX35T4.csv]
2023-12-22 Fix button handling
2023-12-22 Add a macro for setting up profiles
    [LITTLE_INFERNO.csv]
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2023-12-26 Clear the interrupt flag to prevent double calls
    [main.c]
2023-12-26 Add a front panel CAD project
    [front_panel.FCStd]
2023-12-29 Increase the diameter of the LED holes
    [front_panel.FCStd]
2023-12-29 Add spacers to the mounting holes
    [front_panel.FCStd]
2023-12-30 Add a front panel mounting bracket CAD file
    [front_panel_bracket.FCStd]
2023-12-30 Add a gooseneck mounting CAD file
    [gooseneck_mounting.FCStd]
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2023-12-30 Further increase LED holes diameter
    [front_panel.FCStd, front_panel_mask.FCStd]
2023-12-30 Make hole spacers longer
    [front_panel_mask.FCStd]
2023-12-30 Increase the size of button holes
    [front_panel_mask.FCStd]
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2023-12-31 Adjust the hole diameter
    [gooseneck_mounting.FCStd]
2023-12-31 Increase the APB2 prescaler to improve SPI stability
    [main.c, reflow_hot_plate.ioc]
2023-12-31 Reduce the length of spacers
    [front_panel_mask.FCStd]
2024-01-02 Improve the error checking logic
    [fsm_conf.h, main.c]
2024-01-03 Add more solder profiles
    [OLIMEX_SAC305.csv, QUALITEK_DSP863.csv, SMD291SNL.csv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]
2024-01-03 Send the correct payload
    [device_emulator.py]
2024-01-03 Fix the sheet name
    [leds.kicad_sch]
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2024-01-14 Turn on the buzzer when done
    [main.c]
2024-01-14 Make the bracket longer
    [front_panel_bracket.FCStd]
2024-01-25 Use a frame without the logo
    [control_board.kicad_pcb, front_panel.kicad_pcb, heatbed-rounded.kicad_pcb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]
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

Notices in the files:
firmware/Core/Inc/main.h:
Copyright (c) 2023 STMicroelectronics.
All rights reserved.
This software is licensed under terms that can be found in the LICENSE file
